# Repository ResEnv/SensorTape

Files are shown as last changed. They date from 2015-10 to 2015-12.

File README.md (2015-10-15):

#SensorTape Project 

##Introduction 
SensorTape is a sensor network in a form factor of a tape. It allows users to intuitively create large sensor networks. See mode details in the paper from [UIST](http://artem.dementyev.us/wp-content/uploads/2013/10/Sensor_tape_UIST_2015_rev9_FINAL.pdf) conference and a video 
This repository contains all the hardware and software design files to make SensorTape. 

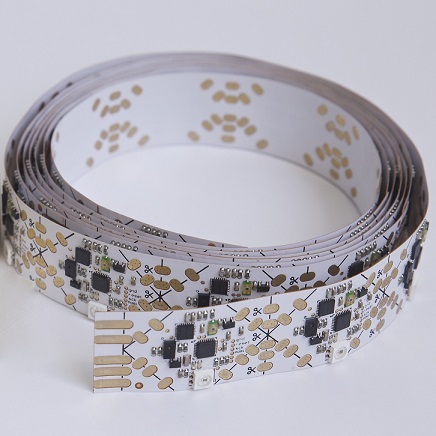
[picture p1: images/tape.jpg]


##Content
Master_hw/ - Hardware files for the master board in Altium format. Can be used to make the board

Slave_hw/ - Hardware files for the tape itself, refered here as the slave. This is the flexible circuit version of the tape 

Prog_adapter_hw/ -  Hardware files for the programming board, use it to program both the slave and the master. 

libraries/ - Collection of the Arduino libraries for the master and the slave. Those libraries are required 

Firmware/ - Firmware for both the master and the slave

SensorTape_Demo_V1/ - Processing sketch for a simple visualization demo. Demonstrates the basics of interfacing with a PC. 

##Firmware 
Add the arduino libraries from the libraries/ folder here to the worspace libraries folder. 
You will need the following libraries Adafruit_NeoPixel, I2C_dev, MPU6050, and VL6180X_I2C_Soft

you will need a programmer and an adapter board (Prog_adapter_hw/) to load the software. I used AVRISP mKII.
you will need to load the bootloader first into the boards. This will set the fuses and the clock frequency. Use the Arduino Micro (3.3V, 8 MHz) for the slaves and Arduino leonardo for the master. Set those before loading the bootloader

##PC software
I used Processing 3. You will need one external library (toxiclibs-complete-0020), it is in the libraries folder. 

##Slave
The slaves are basically the tape. The tape is made of strips with 6 slave nodes. You will need a flexible PCB factory to manufacture. The factories in china are innexpensive and have good quality. They can be found on alibaba.com. Also it is better to get it assembled profesionally, since hand assembly is difficult. I had a lot of problems with the packaging of proximity sensor melting in my reflow owen. 

The programming connector can be hard to attach on the first try, since it is just pressfitted. 

When starting the tape wait about a minute for the IMUs to calibrate, otherwise the orientaion data will drift

##Master
Master moves the data from the slaves to the PC. I am using an ATMega32u4 microcontroller, which works as a USB modem. 

##Known Issues
1. Proximity sometimes dont work if tape is restarted. I suspect that they don't have time to fully discharge. When turning the tape on and off or restarting, wait some time to turn it back on. 
2. The number of nodes is set pn the PC side in the current version. So the nodes dont need to be reset each time PC software is restarted. 

##Aknowledgements
MIT Media Lab, Nan-Wei Gong, Cindy Kao, Nan Zhao, Felix Heibeck, National Sceince Foundation. 
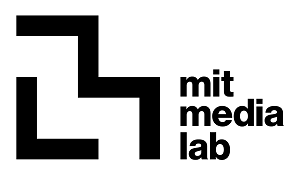
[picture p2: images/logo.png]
MediaLab Logo


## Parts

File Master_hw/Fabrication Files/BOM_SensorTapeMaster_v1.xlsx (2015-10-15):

Description | Quantity | Footprint | Comment | Manufacturer | Mfg Part # | Digikey Part # | Designator
Resistors
RES SMD 4.7K OHM 5% 1/10W 0603 | 2 | 0603 | Generic, can be subsituted with another manufacturer | Yageo | RC0603JR-074K7L | 311-4.7KGRCT-ND | R4,R5
RES SMD 1K OHM 5% 1/10W 0603 | 3 | 0603 | Generic, can be subsituted with another manufacturer | Yageo | RC0603JR-071KL | 311-1.0KGRCT-ND | R1,R3,R9
RES SMD 10K OHM 1% 1/10W 0603 | 2 | 0603 | Generic, can be subsituted with another manufacturer | Stackpole | RMCF0603FT10K0 | RMCF0603FT10K0CT-ND | R6,R12
RES SMD 22 OHM 5% 1/10W 0603 | 2 | 0603 | Generic, can be subsituted with another manufacturer | Yageo | RC0603JR-0722RL | 311-22GRCT-ND | R7,R8
RES ARRAY 330 OHM 4 RES 1206 | 1 | 1206 |  | Panasonic | EXB-38V331JV | Y9331CT-ND | R13
RES SMD 0.0OHM JUMPER 1/10W 0603 | 2 | 603 | Generic, can be subsituted with another manufacturer | Rohm | MCR03EZPJ000 | RHM0.0GCT-ND | R2,R10
Capacitors
CAP CER 0.1UF 16V 10% X7R 0603 | 4 | 0603 | Generic, can be subsituted with another manufacturer | Murata | GRM188R71C104KA01D | 490-1532-1-ND | C3, C4, C5, C8
CAP CER 10UF 6.3V 20% X5R 0603 | 3 | 0603 | Generic, can be subsituted with another manufacturer | Taiyo Yuden | JMK107ABJ106MAHT | 587-3383-1-ND | C1, C2, C9
CAP CER 1UF 10V 10% X7R 0603 | 1 | 0603 | Generic, can be subsituted with another manufacturer | Samsung | CL10B105KP8NNNC | 1276-1946-1-ND | C7
CAP CER 22PF 50V 5% C0G 0603 | 2 | 0603 | Generic, can be subsituted with another manufacturer | TDK | C1608C0G1H220J080AA | 445-1273-1-ND | C10,C11
LEDs
LED 468NM BLUE CLEAR 0603 SMD | 1 | 0603 |  | Lite-On Inc | LTST-C191TBKT | 160-1647-1-ND | L1
LED SUPER RED CLR THIN 0603 SMD | 2 | 0603 |  | Lite-On Inc | LTST-C191KRKT | 160-1447-1-ND | L2, L5
LED RED ORAN CLEAR THIN 0603 SMD | 1 | 0603 |  | Lite-On Inc | LTST-C191KFKT | 160-1445-1-ND | L3
LED WHITE 0603 SMD | 1 | 0603 |  | Lite-On Inc | LTW-C193TS5 | 160-1721-1-ND | L4
LED GREEN CLEAR THIN 0603 SMD | 1 | 0603 |  | Lite-On Inc | LTST-C191KGKT | 160-1446-1-ND | L6
LED RGB WS2812B 5050 W/DVR 10PK | 1 | 5050 |  | Adafruit | 1655 | 1528-1104-ND | L7
Resonators
Crystal 16.0000MHz 30ppm 18pF 60 Ohm | 1 | 4-SMD, No Lead (DFN, LCC) |  | CTS | 405C35D16M00000 | CTX820CT-ND | O2
ICs
IC MCU 8BIT 32KB FLASH 44QFN | 1 | 44-TQFP (10x10) |  | Atmel | ATMEGA32U4-AU | ATMEGA32U4-AU-ND | U5
IC LOAD SW CTRL 1CH SOT-25 | 1 | SOT-25 |  | Diodes inc | AP2280-1WG-7 | AP2280-1WGDICT-ND | U7
IC SWITCH HIGH SIDE SC70-6 | 1 | 6-TSSOP |  | Vishay | SIP32431DR3-T1GE3 | SIP32431DR3-T1GE3CT-ND | U4
MODULE BLUETOOTH V2.1+EDR | 1 | 35-SMD Module |  | Microchip | RN42-I/RM | 740-1038-ND | U1
IC REG LDO 3.3V 0.15A SOT23-5 | 1 | SOT-23-5 |  | Micrel | MIC5205-3.3YM5 TR | 576-1259-1-ND | U6
DNP | 1 | SOT-23-5 | DNP | Micrel | MIC5205-3.3YM5 TR | 576-1259-1-ND | U6
MAGNETOMETER XYZ DIGITAL 10DFN | 1 | 10-DFN (2x2) | Optional | Freescale | MAG3110FCR1 | MAG3110FCR1CT-ND | U3
Connectors
CONN FPC TOP 25POS 1.00MM | 1 |  |  | TE Connectivity | 2-84953-5 | A101410CT-ND | P6
Connector Receptacle USB - micro B | 1 |  |  | Hirose | ZX62-B-5PA(11) | H11634CT-ND | P3
Connector Receptacle USB - min | 1 |  |  | Hirose | UX60SC-MB-5ST(80) | H11671CT-ND | P4
TEST POINT PC MINI .040"D RED | 12 |  | DNP | Keystone electronics | 5000 | 36-5000-ND | TP1, TP2, TP3, TP4, TP5, TP6, TP7, TP8, TP9, TP10, TP11, TP12
Switches
SWITCH TACTILE SPST-NO 0.02A 15V | 1 |  |  | Panasonic | EVQ-Q2B02W | P12931SCT-ND | S1
SWITCH SLIDE SPDT 0.4VA 28V | 1 |  |  | NKK Switches | SS312SAH4-R | 360-2924-1-ND | S2

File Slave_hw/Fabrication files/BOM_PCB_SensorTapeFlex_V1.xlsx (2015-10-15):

Parts for one strip (6 identical circuits)
Description | Quantity | Footprint | Comment | Manufacturer | Mfg Part # | Digikey Part # | Designator
Capacitors
CAP CER 0.1UF 16V 10% X7R 0603 | 24 | 0603 | Generic, can be subsituted with another manufacturer | Murata | GRM188R71C104KA01D | 490-1532-1-ND | C1, C1_1, C1_1_1, C1_1_1_1, C1_1_1_2, C1_1_2, C2, C2_1, C2_1_1, C2_1_1_1, C2_1_1_2, C2_1_2, C5, C5_1, C5_1_1, C5_1_1_1, C5_1_1_2, C5_1_2, C6, C6_1, C6_1_1, C6_1_1_1, C6_1_1_2, C6_1_2
CAP CER 10000PF (10nF) 50V 10% X7R 0603 | 6 | 0603 | Generic, can be subsituted with another manufacturer | Murata | GRM188R71H103KA01D | 490-1512-1-ND | C3, C3_1, C3_1_1, C3_1_1_1, C3_1_1_2, C3_1_2
CAP CER 2200PF 50V 5% NP0 0603 | 6 | 0603 | Generic, can be subsituted with another manufacturer | Murata | GRM1885C1H222JA01D | 490-1459-1-ND | C4, C4_1, C4_1_1, C4_1_1_1, C4_1_1_2, C4_1_2
CAP CER 10UF 6.3V 20% X5R 0603 | 18 | 0603 | Generic, can be subsituted with another manufacturer | Taiyo Yuden | JMK107ABJ106MAHT | 587-3383-1-ND | C7, C7_1, C7_1_1, C7_1_1_1, C7_1_1_2, C7_1_2, C8, C8_1, C8_1_1, C8_1_1_1, C8_1_1_2, C8_1_2, C9, C9_1, C9_1_1, C9_1_1_1, C9_1_1_2, C9_1_2
Resistors
RES SMD 4.7K OHM 5% 1/10W 0603 | 6 | 0603 | Generic, can be subsituted with another manufacturer | Yageo | RC0603JR-074K7L | 311-4.7KGRCT-ND | R3, R3_1, R3_1_1, R3_1_1_1, R3_1_1_2, R3_1_2
RES SMD 1K OHM 1% 1/10W 0603 | 6 | 0603 | Generic, can be subsituted with another manufacturer | Yageo | RC0603FR-071KL | 311-1.00KHRCT-ND | R7, R7_1, R7_1_1, R7_1_1_1, R7_1_1_2, R7_1_2
RES SMD 47K OHM 1% 1/10W 0603 | 12 | 0603 | Generic, can be subsituted with another manufacturer | Yageo | RC0603FR-0747KL | 311-47.0KHRCT-ND | R8, R8_1, R8_1_1, R8_1_1_1, R8_1_1_2, R8_1_2, R9, R9_1, R9_1_1, R9_1_1_1, R9_1_1_2, R9_1_2
RES SMD 330 OHM 1% 1/10W 0603 | 12 | 0603 | Generic, can be subsituted with another manufacturer | Yageo | RC0603FR-07330RL | 311-330HRCT-ND | R10, R10_1, R10_1_1, R10_1_1_1, R10_1_1_2, R10_1_2, R11, R11_1, R11_1_1, R11_1_1_1, R11_1_1_2, R11_1_2
RES SMD 10K OHM 1% 1/10W 0603 | 24 | 0603 | Generic, can be subsituted with another manufacturer | Stackpole Electronics | RMCF0603FT10K0 | RMCF0603FT10K0CT-ND | R1, R1_1, R1_1_1, R1_1_1_1, R1_1_1_2, R1_1_2, R2, R2_1, R2_1_1, R2_1_1_1, R2_1_1_2, R2_1_2, R4, R4_1, R4_1_1, R4_1_1_1, R4_1_1_2, R4_1_2, R6, R6_1, R6_1_1, R6_1_1_1, R6_1_1_2, R6_1_2
Resonators
CER RESONATOR 8.00MHZ SMD | 6 | 3-SMD, Non-Standard |  | Murata | CSTCE8M00G55-R0 | 490-1195-1-ND | O1, O1_1, O1_1_1, O1_1_1_1, O1_1_1_2, O1_1_2
LEDs
WS2812S 6 pin RGB LED | 6 | 5050 | Has to be the 6 pin version (S version) | Worldsemi | WS2812S |  | L1, L1_1, L1_1_1, L1_1_1_1, L1_1_1_2, L1_1_2
LED 468NM BLUE CLEAR 0603 SMD | 6 | 0603 | Generic, can be subsituted with another manufacturer | Lite-On Inc | LTST-C191TBKT | 160-1647-1-ND | L2, L2_1, L2_1_1, L2_1_1_1, L2_1_1_2, L2_1_2
LED SUPER RED CLR THIN 0603 SMD | 6 | 603 | Generic, can be subsituted with another manufacturer | Lite-On Inc | LTST-C191KRKT | 160-1447-1-ND | L3, L3_1, L3_1_1, L3_1_1_1, L3_1_1_2, L3_1_2
ICs
AMBIENT LIGHT SENSOR 1206 SMD | 6 | 1206 |  | Vishay | TEMT6000X01 |  | T1, T1_1, T1_1_1, T1_1_1_1, T1_1_1_2, T1_1_2
GYRO/ACCELEROMETER 6AXIS 24QFN | 6 | QFN24 |  | Invensense | MPU-6050 |  | U1, U1_1, U1_1_1, U1_1_1_1, U1_1_1_2, U1_1_2
ATmega328P-MUR | 6 | 32-VFQFN Exposed Pad |  | Atmel | ATMEGA328P-MU |  | U2, U2_1, U2_1_1, U2_1_1_1, U2_1_1_2, U2_1_2
MOD TIME-OF-FLIGHT 3IN1 12LGA | 6 | 12LGA |  | STMicroelectronics | VL6180XV0NR/1 |  | U3, U3_1, U3_1_1, U3_1_1_1, U3_1_1_2, U3_1_2
IC REG LDO 2.8V 0.15A SOT23-5 | 6 | SOT-23-5 |  | Micrel | MIC5205-2.8YM5 TR |  | U4, U4_1, U4_1_1, U4_1_1_1, U4_1_1_2, U4_1_2,
IC REG LDO 3.3V 0.15A SOT23-5 | 6 | SOT-23-5 |  | Micrel | MIC5205-3.3YM5 TR |  | U5, U5_1, U5_1_1, U5_1_1_1, U5_1_1_2, U5_1_2

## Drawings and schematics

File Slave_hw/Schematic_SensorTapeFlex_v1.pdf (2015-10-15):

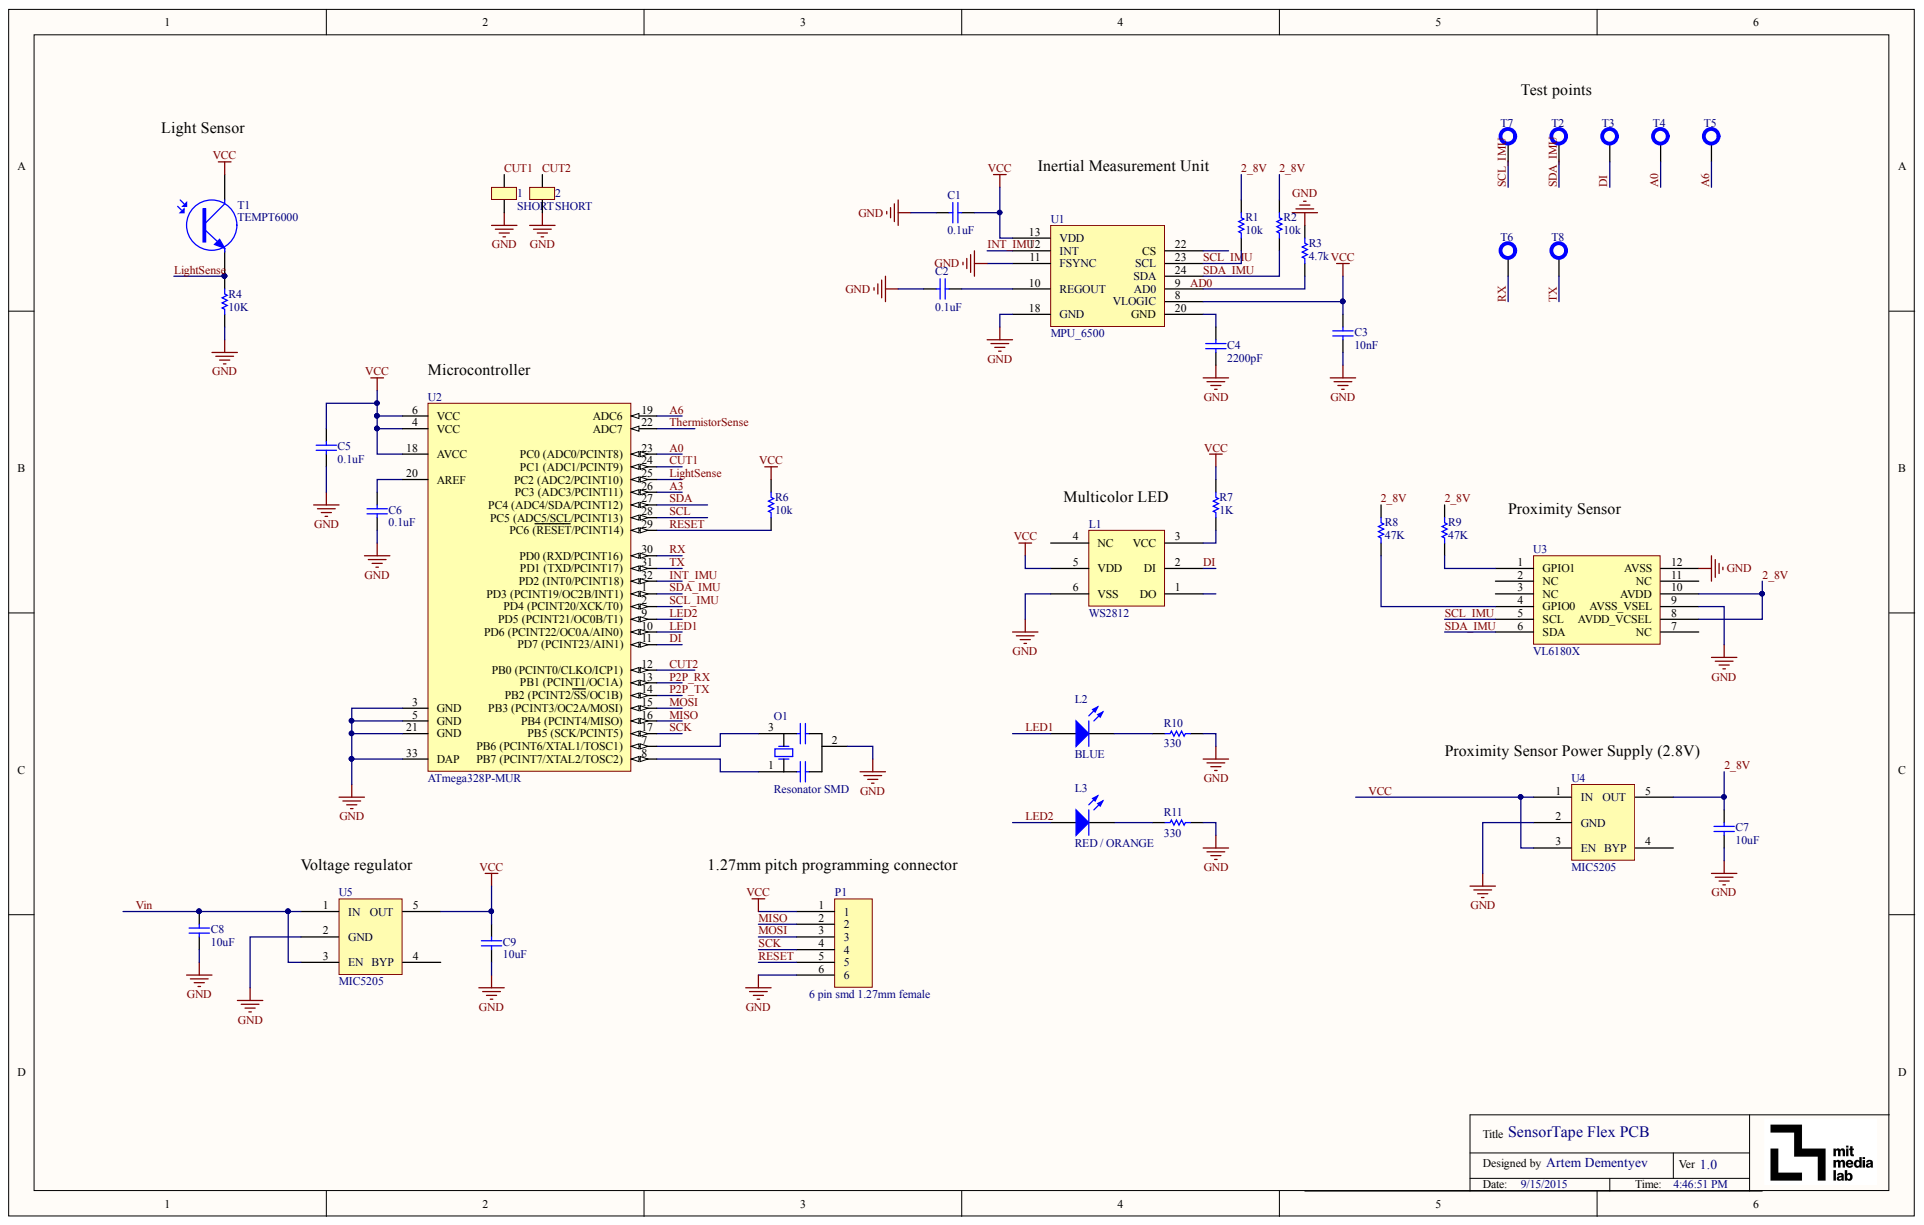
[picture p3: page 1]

Ti t l e Sen s orTape Flex PCB Artem Dementyev

Des igned by | 1 . 0 Ver

Date: 9/15/2015 | Ti me: 4:46:51 PM

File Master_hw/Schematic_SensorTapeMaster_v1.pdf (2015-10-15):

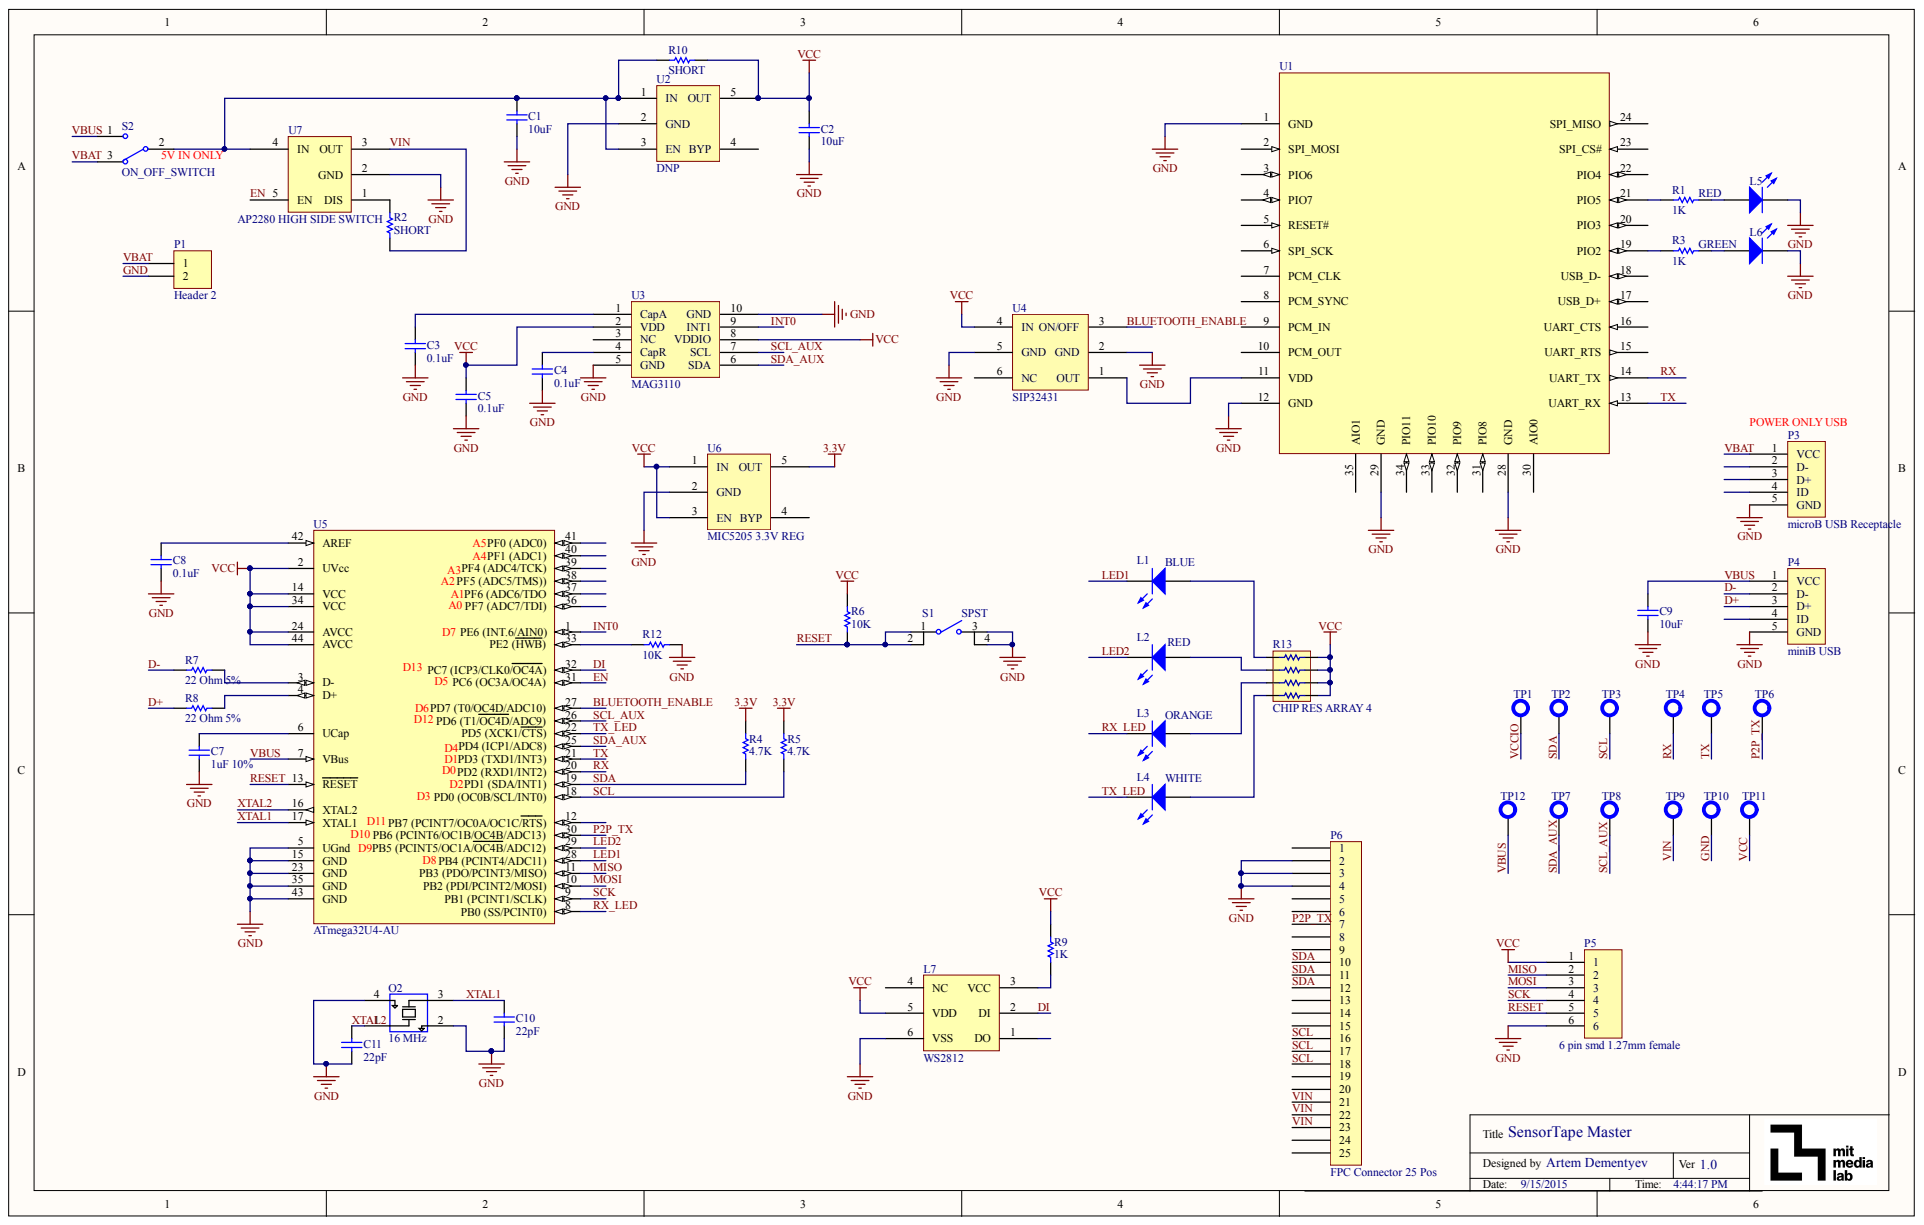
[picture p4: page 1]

Designed by Artem Dementyev | Ver 1.0

Date: 9/15/2015 | Time: 4:44:17 PM

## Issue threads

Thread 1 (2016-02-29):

Why not PJON?

gioblu, 2016-02-29:
Hi there, I really liked your project and how you engineered it. Maybe my opinion could be a little biased because I am the main developer, but, I think you should consider PJON as an alternative to 1-Wire. Good luck with SensorTape.

gioblu, 2016-02-29:
Reading the attached UIST document I see in the sections "limitations" and "future work" some issues PJON could accomplish efficiently.

adementyev, 2016-03-01:
Hi, thanks for sharing the protocol. It looks really interesting, and very nice implementation. I will definitely check it out in more details.
I looked at 1-wire and few other protocols, and there wasn't any good alternatives to I2C at the time.
I am currently trying to use serial over RS-485, it can be pretty fast with 0.5Mb/sec and 256 slaves with 8MHz clock.

Some quick questions about PJON:
What limits the speed to 5.3 kbit/sec? Could you use serial module to speed it up, instead of doing in software?
Is 254 devices a physical limit? Realistically they might add capacitance and impedance to the bus, thus limiting number of devices to a smaller number

gioblu, 2016-03-01:
Ciao @adementyev thank you again, and I am really pleased buy your comments on PJON :+1:

The 5.3kB/s is a bottleneck imposed by `micros()` resolution (4 microseconds, crap) infact for me is astonishing to see it working so precisely at these speeds.

I sincerely never considered the hardware serial usage and I would not take it for bias :+1:
Could you explain me in more detail what you imagine?

Because of the not enormous communication speed and the initial padding bits or sync procedure the capacitance effect is mild, I tried up to 30 devices (i don't have more) and it worked flawlessly and other users had similar results. Consider that PJON works flawlessly using a human body as a conductor passing from the left hand to the right one without effect in reliability!!

I also will add in 1.2 tri-state logic to completely exclude from the circuit all devices are not actively or passively using it, to further reduce the average capacitance on the bus.

Thank you again and compliments for you build.

gioblu, 2016-03-01:
@adementyev Serial over RS485 is really a reliable and professional choice, for sure. And is what in general I suggest for many applications, but, I think RS485 has a little old concept and its bias for reliability in some way limits its use in a real multimaster plug&use environment (a master collission could physically blow up a driver). PJON in some way is an attempt to fill this gap.

What I mean is that could be interesting to cut a piece of your tape and let it work indipendently as a single entity or temporarily join it to another one to higher the new entity's capability. On the other side could be nice to phisically build a network of buses (tape sections) in every possible configuration using packet routing with plug and use capability.

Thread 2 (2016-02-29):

Where to print

rmeertens, 2016-02-29:
Hey guys,

Just found your work, awesome stuff. You mentioned you found somebody on alibaba. Can I have a link to the supplier?

jonnycowboy, 2016-02-29:
Also interested in an answer to this especially in a high temperature flexible tape (ex DuPont Pyralux HT).

adementyev, 2016-03-01:
For assembly/manufacturing we used a contract manufacturer company: http://aqs-inc.com/
We sourced parts and supplies from this company http://www.hkkzd.com/
Recently, places such PCB pool https://www.pcb-pool.com/ppus/order_productconfiguration_js.html
started offering flex circuits. This is a lot more convenient for prototyping.

rmeertens, 2016-03-01:
Awesome. Thank you very much for your reply!

Closed 2016-06-22.

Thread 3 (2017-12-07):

SensorTapeFlex_SW_V2.ino is not compiling

imguilherme, 2017-12-07:
Hi there.

I'm trying to compile `SensorTapeFlex_SW_V2.ino` but until now I had not success.

I've imported the whole necessary libraries but the error bellow appeared to me.

Can you help me ?

`
/var/folders/dj/w1brmcbj5dz1qcyspnyhwtcc0000gn/T//cc5bGKDF.ltrans1.ltrans.o: In function `I2Cdev::i2c_read(bool)':
/Users/guilherme/Documents/Arduino/libraries/I2C_dev/I2Cdev.cpp:1808: undefined reference to `ass_i2c_delay_half'
/Users/guilherme/Documents/Arduino/libraries/I2C_dev/I2Cdev.cpp:1808:(.text+0xd14): relocation truncated to fit: R_AVR_13_PCREL against undefined symbol `ass_i2c_delay_half'
/Users/guilherme/Documents/Arduino/libraries/I2C_dev/I2Cdev.cpp:1808: undefined reference to `ass_i2c_delay_half'
/Users/guilherme/Documents/Arduino/libraries/I2C_dev/I2Cdev.cpp:1808:(.text+0xd18): relocation truncated to fit: R_AVR_13_PCREL against undefined symbol `ass_i2c_delay_half'
/Users/guilherme/Documents/Arduino/libraries/I2C_dev/I2Cdev.cpp:1808: undefined reference to `ass_i2c_wait_scl_high'
/Users/guilherme/Documents/Arduino/libraries/I2C_dev/I2Cdev.cpp:1808:(.text+0xd24): relocation truncated to fit: R_AVR_13_PCREL against undefined symbol `ass_i2c_wait_scl_high'
/Users/guilherme/Documents/Arduino/libraries/I2C_dev/I2Cdev.cpp:1808: undefined reference to `ass_i2c_delay_half'
/Users/guilherme/Documents/Arduino/libraries/I2C_dev/I2Cdev.cpp:1808:(.text+0xd44): relocation truncated to fit: R_AVR_13_PCREL against undefined symbol `ass_i2c_delay_half'
/Users/guilherme/Documents/Arduino/libraries/I2C_dev/I2Cdev.cpp:1808: undefined reference to `ass_i2c_wait_scl_high'
/Users/guilherme/Documents/Arduino/libraries/I2C_dev/I2Cdev.cpp:1808:(.text+0xd50): relocation truncated to fit: R_AVR_13_PCREL against undefined symbol `ass_i2c_wait_scl_high'
/Users/guilherme/Documents/Arduino/libraries/I2C_dev/I2Cdev.cpp:1808: undefined reference to `ass_i2c_delay_half'
/Users/guilherme/Documents/Arduino/libraries/I2C_dev/I2Cdev.cpp:1808:(.text+0xd52): relocation truncated to fit: R_AVR_13_PCREL against undefined symbol `ass_i2c_delay_half'
/var/folders/dj/w1brmcbj5dz1qcyspnyhwtcc0000gn/T//cc5bGKDF.ltrans1.ltrans.o: In function `ass_i2c_write':
/Users/guilherme/Documents/Arduino/libraries/I2C_dev/I2Cdev.cpp:1738: undefined reference to `ass_i2c_delay_half'
/Users/guilherme/Documents/Arduino/libraries/I2C_dev/I2Cdev.cpp:1738:(.text+0xd82): relocation truncated to fit: R_AVR_13_PCREL against undefined symbol `ass_i2c_delay_half'
/Users/guilherme/Documents/Arduino/libraries/I2C_dev/I2Cdev.cpp:1738: undefined reference to `ass_i2c_wait_scl_high'
/Users/guilherme/Documents/Arduino/libraries/I2C_dev/I2Cdev.cpp:1738:(.text+0xd90): relocation truncated to fit: R_AVR_13_PCREL against undefined symbol `ass_i2c_wait_scl_high'
/Users/guilherme/Documents/Arduino/libraries/I2C_dev/I2Cdev.cpp:1738: undefined reference to `ass_i2c_delay_half'
/Users/guilherme/Documents/Arduino/libraries/I2C_dev/I2Cdev.cpp:1738:(.text+0xd98): relocation truncated to fit: R_AVR_13_PCREL against undefined symbol `ass_i2c_delay_half'
/Users/guilherme/Documents/Arduino/libraries/I2C_dev/I2Cdev.cpp:1738: undefined reference to `ass_i2c_delay_half'
/Users/guilherme/Documents/Arduino/libraries/I2C_dev/I2Cdev.cpp:1738:(.text+0xda4): relocation truncated to fit: R_AVR_13_PCREL against undefined symbol `ass_i2c_delay_half'
/Users/guilherme/Documents/Arduino/libraries/I2C_dev/I2Cdev.cpp:1738: undefined reference to `ass_i2c_wait_scl_high'
/Users/guilherme/Documents/Arduino/libraries/I2C_dev/I2Cdev.cpp:1738:(.text+0xdb2): additional relocation overflows omitted from the output
/Users/guilherme/Documents/Arduino/libraries/I2C_dev/I2Cdev.cpp:1738: undefined reference to `ass_i2c_delay_half'
/var/folders/dj/w1brmcbj5dz1qcyspnyhwtcc0000gn/T//cc5bGKDF.ltrans1.ltrans.o: In function `ass_i2c_stop':
/Users/guilherme/Documents/Arduino/libraries/I2C_dev/I2Cdev.cpp:1661: undefined reference to `ass_i2c_delay_half'
/Users/guilherme/Documents/Arduino/libraries/I2C_dev/I2Cdev.cpp:1661: undefined reference to `ass_i2c_delay_half'
/Users/guilherme/Documents/Arduino/libraries/I2C_dev/I2Cdev.cpp:1661: undefined reference to `ass_i2c_wait_scl_high'
/Users/guilherme/Documents/Arduino/libraries/I2C_dev/I2Cdev.cpp:1661: undefined reference to `ass_i2c_delay_half'
/var/folders/dj/w1brmcbj5dz1qcyspnyhwtcc0000gn/T//cc5bGKDF.ltrans1.ltrans.o: In function `I2Cdev::i2c_start(unsigned char)':
/Users/guilherme/Documents/Arduino/libraries/I2C_dev/I2Cdev.cpp:1572: undefined reference to `ass_i2c_wait_scl_high'
/Users/guilherme/Documents/Arduino/libraries/I2C_dev/I2Cdev.cpp:1572: undefined reference to `ass_i2c_delay_half'
collect2: error: ld returned 1 exit status
exit status 1
`

Closed 2019-11-21.

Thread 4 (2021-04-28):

Compile Problem in "SensorTapeFlex_SW_V2.ino"

ZJUZZH, 2021-04-28:

Closed 2021-05-04.

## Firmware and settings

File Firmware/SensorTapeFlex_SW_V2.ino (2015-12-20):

//This is for tape flexible pcb version of the tape (SensorTapeFlex_V1)
//Use Arduino Micro (8MHz, 3.3V)
//Author: Artem Dementyev
//Modified on Septeber 9,2015

//I2C pins are switched from the Rigid PCB Version: 
//CHANGE the I2Cdev.h  SDA_PIN and SCL_PIN 

 
#include "I2Cdev.h"
#include "MPU6050_6Axis_MotionApps20.h"
#include <SPI.h>
#include <Wire.h>
#include <SoftwareSerial.h>
#include <Adafruit_NeoPixel.h>
#include "VL6180X_I2C_Soft.h"

MPU6050 mpu;
SoftwareSerial p2pSerial(9,10); //RX, TX

#define PIN_RGB_LED    7
#define LED_BLUE       6
#define LED_RED        5
#define ADC_LIGHT_PIN  A2
//#define CUT_1     A1      
//#define CUT_2     8
#define NUMPIXELS      1  
#define VL6180X_ADDRESS 0x29


bool blinkState = false;

// MPU control/status vars
bool dmpReady = false;  // set true if DMP init was successful
uint8_t mpuIntStatus;   // holds actual interrupt status byte from MPU
uint8_t devStatus;      // return status after each device operation (0 = success, !0 = error)
uint16_t packetSize;    // expected DMP packet size (default is 42 bytes)
uint16_t fifoCount;     // count of all bytes currently in FIFO
uint8_t fifoBuffer[64]; // FIFO storage buffer

// orientation/motion vars
Quaternion q;           // [w, x, y, z]         quaternion container
VectorInt16 aa;         // [x, y, z]            accel sensor measurements
VectorInt16 aaReal;     // [x, y, z]            gravity-free accel sensor measurements
VectorInt16 aaWorld;    // [x, y, z]            world-frame accel sensor measurements
VectorFloat gravity;    // [x, y, z]            gravity vector

// packet structure for InvenSense teapot demo
uint8_t teapotPacket[14] = { '$', 0x02, 0,0, 0,0, 0,0, 0,0, 0x00, 0x00, '\r', '\n' };
//global variables
int numberOfSensors = 3;
int deviceType = 1;
int deviceID = 0; 
int cut1pin = A1; 
int cut2pin = 8; 
boolean startUp = true; 
int incomingByte = 0;
byte val1; 
byte val2;  
int lightAnalogRead = 2000; 
int thermistorAnalogRead = 3000; 
int positionAnalogRead = 4000;
String valueString = "a"; 
byte valAll[1]; 
uint8_t distanceReading =0x10; 
uint8_t masterReceive[3] = {0x00,0x00,0x00} ;

Adafruit_NeoPixel pixels = Adafruit_NeoPixel(NUMPIXELS, PIN_RGB_LED, NEO_GRB + NEO_KHZ800);
VL6180x distanceSensor(VL6180X_ADDRESS);

// ================================================================
// ===               INTERRUPT DETECTION ROUTINE FOR IMU        ===
// ================================================================

volatile bool mpuInterrupt = false;     // indicates whether MPU interrupt pin has gone high
void dmpDataReady() {
    mpuInterrupt = true;
}

// ================================================================
// ===                      INITIAL SETUP                       ===
// ================================================================

void setup() {
    //set pins  
    pinMode(LED_BLUE, OUTPUT);   
    pinMode(LED_RED, OUTPUT); 
    digitalWrite(LED_BLUE, HIGH); 
  
    SPI.begin();
    p2pSerial.begin(9600);
    delay(50); 
  
    //Wait until data from peer to peer network
    while(true){ 
      if(p2pSerial.available()>1) { 
        if(p2pSerial.read()==200) { 
          incomingByte = p2pSerial.read();
          //assign address from incoming data  
          deviceID=incomingByte; 
  
          //send data to the next device
          p2pSerial.write(200);
          p2pSerial.write(incomingByte+1);
          digitalWrite(LED_BLUE, LOW);  
          break; 
        }
      }
    }//end while
    p2pSerial.end(); 
  
    I2Cdev::i2c_init();

    //Start imu and proximity initialization
    mpu.initialize();
    distanceSensor.VL6180xInit();
  
    devStatus = mpu.dmpInitialize();
    distanceSensor.VL6180xDefautSettings();
    distanceSensor.VL6180x_setRegister(VL6180X_SYSTEM_FRESH_OUT_OF_RESET  , 0x00); 
    distanceSensor.VL6180x_setRegister(VL6180X_SYSRANGE_START, 0x01); //Start the 100ms continous operation.
   
    // supply your own gyro offsets here, scaled for min sensitivity
    mpu.setXGyroOffset(220);
    mpu.setYGyroOffset(76);
    mpu.setZGyroOffset(-85);
    mpu.setZAccelOffset(1788); // 1688 factory default for my test chip
    
    
    mpu.setDMPEnabled(true);
    // enable Arduino interrupt detection
    mpuIntStatus = mpu.getIntStatus();
    dmpReady = true;
    packetSize = mpu.dmpGetFIFOPacketSize(); 
    
    Wire.begin(deviceID); // Start I2C Bus as a Slave (Device Number 2)
    Wire.onRequest(requestEvent); // register event to send data to master (respond to requests)
    Wire.onReceive(receiveEvent); //register even to receice data from master
    attachInterrupt(0, dmpDataReady, RISING);
     
    pixels.begin(); // This initializes the NeoPixel library.
    pixels.setPixelColor(0, pixels.Color(0,10,0)); // Moderately bright green color.
    pixels.show(); // This sends the updated pixel color to the hardware.    
}//end setup

// ================================================================
// ===                    MAIN PROGRAM LOOP                     ===
// ================================================================

void loop() {
      //This is the MAIN LOOP
     while (!mpuInterrupt && fifoCount < packetSize) {
            //DO nothing, wait for interrupts 
      }//end while
    
    //STEPPING OUT OF THE LOOP FOR INTERRUPT  
    // reset interrupt flag and get INT_STATUS byte
    mpuInterrupt = false;
    mpuIntStatus = mpu.getIntStatus();
    
    // get current FIFO count
    fifoCount = mpu.getFIFOCount();
    
    if ((mpuIntStatus & 0x10) || fifoCount == 1024) {
        // reset so we can continue cleanly
        mpu.resetFIFO();
    //    Serial.println(F("FIFO overflow!"));

    // otherwise, check for DMP data ready interrupt (this should happen frequently)
    } else if (mpuIntStatus & 0x02) {
        // wait for correct available data length, should be a VERY short wait
        while (fifoCount < packetSize) fifoCount = mpu.getFIFOCount();

        // read a packet from FIFO
        mpu.getFIFOBytes(fifoBuffer, packetSize);
        
        // track FIFO count here in case there is > 1 packet available
        // (this lets us immediately read more without waiting for an interrupt)
        fifoCount -= packetSize;

       
        // display quaternion values in InvenSense Teapot demo format:
        teapotPacket[2] = fifoBuffer[0];
        teapotPacket[3] = fifoBuffer[1];
        teapotPacket[4] = fifoBuffer[4];
        teapotPacket[5] = fifoBuffer[5];
        teapotPacket[6] = fifoBuffer[8];
        teapotPacket[7] = fifoBuffer[9];
        teapotPacket[8] = fifoBuffer[12];
        teapotPacket[9] = fifoBuffer[13];
        teapotPacket[11]++; // packetCount, loops at 0xFF on purpose

       //get data from priximity sensor 
       if(!startUp) {  
         noInterrupts();
         char range_status = distanceSensor.VL6180x_getRegister(VL6180X_RESULT_INTERRUPT_STATUS_GPIO) & 0x07;
         // wait for new measurement ready status
         if (range_status == 0x04) {
             distanceReading = distanceSensor.VL6180x_getRegister(VL6180X_RESULT_RANGE_VAL); 
             distanceSensor.VL6180x_setRegister(VL6180X_SYSTEM_INTERRUPT_CLEAR, 0x07);
             distanceSensor.VL6180x_setRegister(VL6180X_SYSRANGE_START, 0x01); //Start Single shot mode
             digitalWrite(LED_BLUE, !digitalRead(LED_BLUE));
         }//end if
         interrupts();
       }
    }//end else if 
}//end loop

//This function assembles a reply to a master's request
void requestEvent()
{
    //The communication sends the number of sensors and type of device. 
    if (startUp) { 
        byte a = deviceID & 0xFF; //Use this format to send 16bit integer to java. 
        byte b = (deviceID >>8 ) & 0xFF;
        
        byte c = numberOfSensors & 0xFF; ; 
        byte d = (numberOfSensors >>8 ) & 0xFF;
        
        byte e = deviceType & 0xFF; ; 
        byte f = (deviceType >>8 ) & 0xFF;
        
        int tempread = digitalRead(cut1pin); 
        byte g = tempread & 0xFF; ; 
        byte h = (tempread >>8 ) & 0xFF;     
        
        tempread = digitalRead(cut2pin); 
        byte i = tempread & 0xFF; ; 
        byte j = (tempread >>8 ) & 0xFF;   
        
        tempread = digitalRead(cut2pin); 
        byte k = tempread & 0xFF; ; 
        byte l = (tempread >>8 ) & 0xFF; 
        
        tempread = digitalRead(cut2pin); 
        byte m = tempread & 0xFF; ; 
        byte n = (tempread >>8 ) & 0xFF; 
        
        byte All [] = {a,b,c,d,e,f,g,h,i,j,k,l,m,n};  
           
        Wire.write(All, 14); // respond with message 
        startUp = false;
    } 

    //Otterwise, send data from the on-board sensors. 
    else { 
        digitalWrite(LED_RED, HIGH);
        lightAnalogRead = analogRead(ADC_LIGHT_PIN); // Read light value 
        thermistorAnalogRead = lightAnalogRead; //Read thermistor valie
        //positionAnalogRead = analogRead(A1); //Read position
        
        byte a = deviceID & 0xFF;
        byte b = (deviceID >>8 ) & 0xFF;
        
        byte c = lightAnalogRead & 0xFF; ; 
        byte d = (lightAnalogRead >>8 ) & 0xFF;
     
        byte e = thermistorAnalogRead & 0xFF; ; 
        byte f = (thermistorAnalogRead >>8 ) & 0xFF;
        
        byte g = distanceReading & 0xFF;
        byte h = (0x00 >>8 ) & 0xFF;
       
        byte All [] = {a,b,c,d,e,f,g,h, 
                      fifoBuffer[1], fifoBuffer[0], 
                      fifoBuffer[5], fifoBuffer[4], 
                      fifoBuffer[9], fifoBuffer[8],
                      fifoBuffer[13], fifoBuffer[12]};     
        
        byte *mypointer; 
        mypointer = All;
        byte crc8 = CRC8(mypointer, 16);
        
        byte data [] = {a,b,c,d,e,f,g,h, 
              fifoBuffer[1], fifoBuffer[0], 
              fifoBuffer[5], fifoBuffer[4], 
              fifoBuffer[9], fifoBuffer[8],
              fifoBuffer[13], fifoBuffer[12],
              crc8, 0x00}; 
                        
        Wire.write(data, 18); 
        digitalWrite(LED_RED, LOW);    
    }//end else        
}//end requestEvent

//This function sets led color based on master command
void receiveEvent(int howMany)
{
  if (Wire.available()) {    
      masterReceive[0] = Wire.read(); 
      masterReceive[1] = Wire.read(); 
      masterReceive[2] = Wire.read(); 
  }
     pixels.setPixelColor(0, pixels.Color(masterReceive[0],masterReceive[1],masterReceive[2])); 
     pixels.show();
}

int readInternalTemperature() {
    int result;
    // Read temperature sensor against 1.1V reference
    ADMUX = _BV(REFS1) | _BV(REFS0) | _BV(MUX3);
    delay(2); // Wait for Vref to settle
    ADCSRA |= _BV(ADSC); // Convert
    while (bit_is_set(ADCSRA,ADSC));
    result = ADCL;
    result |= ADCH<<8;
    //result = (result - 125) * 1075;
    return result;
}

//CRC-8 - based on the CRC8 formulas by Dallas/Maxim
//From here: 
///http://www.leonardomiliani.com/en/2013/un-semplice-crc8-per-arduino/
byte CRC8(const byte *data, byte len) {
  byte crc = 0x00;
  while (len--) {
    byte extract = *data++;
    for (byte tempI = 8; tempI; tempI--) {
      byte sum = (crc ^ extract) & 0x01;
      crc >>= 1;
      if (sum) {
        crc ^= 0x8C;
      }
      extract >>= 1;
    }
  }
  return crc;
}

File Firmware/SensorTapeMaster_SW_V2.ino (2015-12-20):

//this code is for the  SensorTapeMaster_v1 with build in USB transciever (ATmega32u4)
//Select the Arduino Leonardo board. (16MHz, 5V)
//Author: Artem Dementyev
//Date modified: September 13, 2015
//TODO: The neopixel light doesn't work on that board. Must be something with the clock being 16 Mhz
//uUisng arduino 1.0.5

//Libraries
#include <Wire.h>
#include <SoftwareSerial.h>
#include <Adafruit_NeoPixel.h>

//Global definitions
#define BT_ENABLE      6
#define TAPE_POWER     5
#define LED_BLUE       8 
#define LED_RED        9
#define PIN_NEOPIXEL   13
#define P2P_SERIAL_RX  11
#define P2P_SERIAL_TX  10
#define NUMPIXELS      1 

//Global variables
boolean lookUpPresence[128];
int lookUpNumberOfSensors[128]; 
unsigned int deviceID = 200;
int x = 0;

Adafruit_NeoPixel pixels = Adafruit_NeoPixel(NUMPIXELS, PIN_NEOPIXEL, NEO_GRB + NEO_KHZ800);
SoftwareSerial p2pSerial(P2P_SERIAL_RX,P2P_SERIAL_TX); //RX, TX

void setup() {                
  // initialize the digital pin as an output.
  pinMode(LED_BLUE, OUTPUT);   
  pinMode(BT_ENABLE, OUTPUT);
  pinMode(TAPE_POWER,OUTPUT);
  digitalWrite(BT_ENABLE,HIGH); //LOW - turn off
  digitalWrite(TAPE_POWER, HIGH);// HIGH - tape on 
  Serial.begin(115200);
  Serial.println("Connected");
  Wire.begin();  // Start I2C Bus as Master
  
  //This changes the I2C global bus speed to 400 kHz (max) 
  //#define TWI_FREQ_NUNCHUCK 400000L
  //#define CPU_FREQ 16000000L
  //TWBR = ((CPU_FREQ / TWI_FREQ_NUNCHUCK) - 16) / 2;
  
  delay(10);
  p2pSerial.begin(9600);
  
  pixels.begin(); // This initializes the NeoPixel library.
  pixels.setPixelColor(0, pixels.Color(100,15,15)); // Moderately bright green color.
  pixels.show(); // This sends the updated pixel color to the hardware.

  //Start the peer to peer transmission. 
  delay(90); 
  int foo = 200;
  p2pSerial.write(foo);
  foo=1; 
  p2pSerial.write(foo); 
  delay(4000);//master should transmit only after slaves are ready

  //see how many slaves are present
  findWhoIsAround();
  
   pixels.begin(); // This initializes the NeoPixel library.
   pixels.setPixelColor(0, pixels.Color(10,30,10)); // Moderately bright green color.
   pixels.show(); // This sends the updated pixel color to the hardware.
   
}

void loop() {
  //Blink the LED
  digitalWrite(LED_BLUE, !digitalRead(LED_BLUE)); 

  //Poll slaves in order
  for(int i=0; i<128; i++) { 
    if(lookUpPresence[i]) { 
      if (i == 8 ) {
      requestFromDevice(i,18); //this is for the motion sensor 
    }
    else requestFromDevice(i,18);
    }
  }//end for

  //If the master wants to send something to a slave
  if (Serial.available() >= 3) { 
    delay(5);  //The communications sometimes crashes without this delay. 
    int whereToSend = Serial.read() *256; 
    whereToSend = whereToSend + Serial.read(); 
    byte command1 = Serial.read();
    byte command2 = Serial.read(); 
    byte command3 = Serial.read(); 
    delay(15); //The communications might crash without this delay 
    //Check just in case if the commands are below 128. This is the maximum that can be sent by java Char (-127 to 127) 
    if (command1 <128 && command2<128 & command3<128) { 
    sendByteToSlave(whereToSend, command1,command2,command3);
    }
    Serial.flush();
  }
}//end loop


void setToZeros() { 
  unsigned int deviceID = 200 ;
}//end setToZeros


void findWhoIsAround() { 
    for (int i=0; i<128; i++) { 
      requestFromDeviceDuringStart(i,14); 
      if(deviceID==i){ 
        Serial.print(i);
        Serial.println(" is present");
        lookUpPresence[i] = true; 
      } 
      else {
        lookUpPresence[i] = false;
      } 
      //delay(1000);
      digitalWrite(LED_RED, !digitalRead(LED_RED)); 
  }//end for
}//end findwhoIsAround



void requestFromDevice(int device, int bytes) { 
    unsigned char inputArray[bytes];
    
    unsigned char dataArray[bytes-2];
    
    setToZeros(); 
   if (Wire.requestFrom(device, bytes)>0) {  
      while(Wire.available())    
      { 
        unsigned char  c= Wire.read(); 
        inputArray[x] = c; 
        x++;   
      }//end while 
      
      x = 0; 
      
      for (int i=0; i<bytes-2; i++) { 
        dataArray[i] = inputArray[i];
      }
      
      byte *mypointer; 
      mypointer = dataArray;
      byte crc8 = CRC8(mypointer, 16);
      byte crc8in = inputArray[bytes-2];
      
      if(crc8 == crc8in) { 
        inputArray[bytes-2]= 0x02;
        inputArray[bytes-1]= 0x00;
      }
      else{ 
        inputArray[bytes-2]= 0x01;
        inputArray[bytes-1]= 0x00;
      }
        
      
     
      //Send data to the PC immidiately. 
      Serial.print("S");
      Serial.print(",");
      for(int i=0; i<bytes; i = i+2) { 
        Serial.print((inputArray[i+1]<<8) + inputArray[i]);
        if (i==bytes-2) { 
        //DO nothing
          }
        else
          Serial.print(",");
      }
      Serial.println(" ");
      deviceID = (inputArray[1]<<8) + inputArray[0];   
      
      
      /*
     for(int i=0; i<bytes-2; i++) { 
       Serial.print(dataArray[i],HEX); 
       Serial.print(","); 
     }
     Serial.print(",");
      Serial.print(crc8);
      Serial.print(","); 
      Serial.print(crc8in);
      Serial.println(" ");
      */
      
      
   }//end if 
 
 
     //Didnt find the device.
     else {
      Serial.print("S");
      Serial.print(",");
      Serial.print(device);
      Serial.print(",");
      for(int i=2; i<bytes; i = i+2) { 
        Serial.print(100);
        if (i==bytes-2) { 
        //DO nothing
          }
        else
          Serial.print(",");
      }
      Serial.println(" ");
      deviceID = device;  
     
   }
   
    
    
    
}

//This function is used to get information about the types of sensors. 
void requestFromDeviceDuringStart(int device, int bytes) { 
    unsigned char inputArray[bytes] ;
    setToZeros(); 
    if (Wire.requestFrom(device, bytes)>0) {   
      while(Wire.available())    // slave may send less than requested
      { 
        unsigned char  c= Wire.read(); 
        inputArray[x] = c; 
        x++;   
      }
      x = 0; 

      //Send to the PC immidiately 
      Serial.print("A");
      Serial.print(",");
      for(int i=0; i<bytes; i = i+2) { 
        Serial.print((inputArray[i+1]<<8) + inputArray[i]);
        if (i==bytes-2) { 
        //DO nothing
          }
        else
          Serial.print(",");
      }
      Serial.println(" ");
      deviceID = (inputArray[1]<<8) + inputArray[0];
      delay(5); //was 5 before
    }
} //end requestFromDeviceDuringStart

void sendByteToSlave(int address, uint8_t command1, uint8_t command2, uint8_t command3) { 
  Wire.beginTransmission(address); 
  Wire.write(command1); 
  Wire.write(command2); 
  Wire.write(command3); 
  Wire.endTransmission(); 
}  //end sendByteToSlave
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
